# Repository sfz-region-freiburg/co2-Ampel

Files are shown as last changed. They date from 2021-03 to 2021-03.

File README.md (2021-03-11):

# CO2 Ampel
Hier findest du alle Informationen zur CO2 Ampel des Schülerforschungszentrum Region Freiburg e.V.

## Struktur
* [documentation](https://github.com/sfz-region-freiburg/co2-Ampel/tree/main/documentation) (Anleitungen und andere Dokumente)
* [electronic](https://github.com/sfz-region-freiburg/co2-Ampel/tree/main/electronics) (Schaltplan, PCB-Layout, EAGLE Daten, Gerber Daten)
* [firmware](https://github.com/sfz-region-freiburg/co2-Ampel/tree/main/firmware/CO2_Ampel_Display_1.5) (Arduino Code)
* [images](https://github.com/sfz-region-freiburg/co2-Ampel/tree/main/images) (Bilder und Grafiken)

## Die CO2 Ampel
CO2 Ampel

## Funktion der CO2 Ampel
* Ampelfarbe entsprechend der Raumluftqualität
* Bei überschreiten von 1000 ppm akustisches Signal (alle 5 Minuten) Blitzlicht (alle 5 Sekunden)
* Akkulaufzeit von ca. 20 Stunden

Hintergrundinformationen:
Außenluft hat üblicherweise eine CO2 Konzentration von 350 bis 450 ppm.

**Richtwerte für Raumluftqualität:**

kleiner 800 ppm | gut
800-1000 ppm | mittel
größer 1000 ppm | mäßig 
Spätestens jetzt sollte gelüftet werden.

## Details zum Aufbau 
[Findest du unter documentation](https://github.com/sfz-region-freiburg/co2-Ampel/tree/main/documentation)

# Gefördert durch:
Gisela und Erwin Sick Stiftung (https://www.sick-stiftung.org/ges/?target=_blank)

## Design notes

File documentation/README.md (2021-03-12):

# Aufbau der CO2 Ampel
Die CO2 Ampel besteht aus relativ wenigen Komponenten.

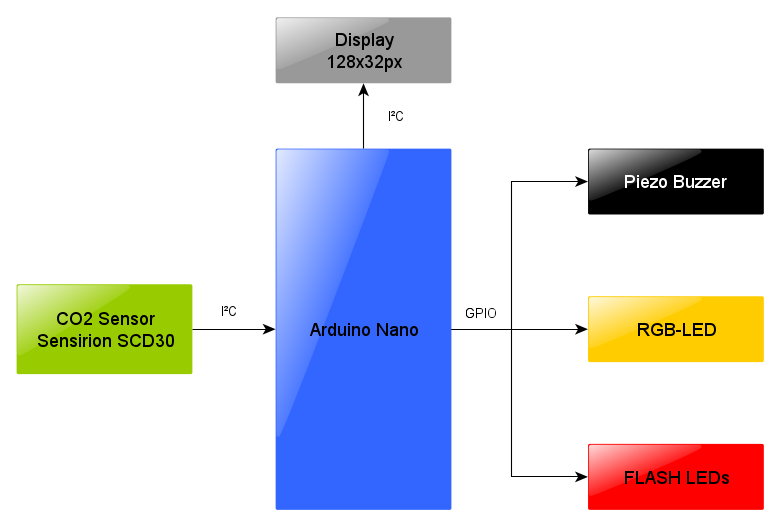
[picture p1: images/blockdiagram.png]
CO2 Ampel - Blockschaltbild


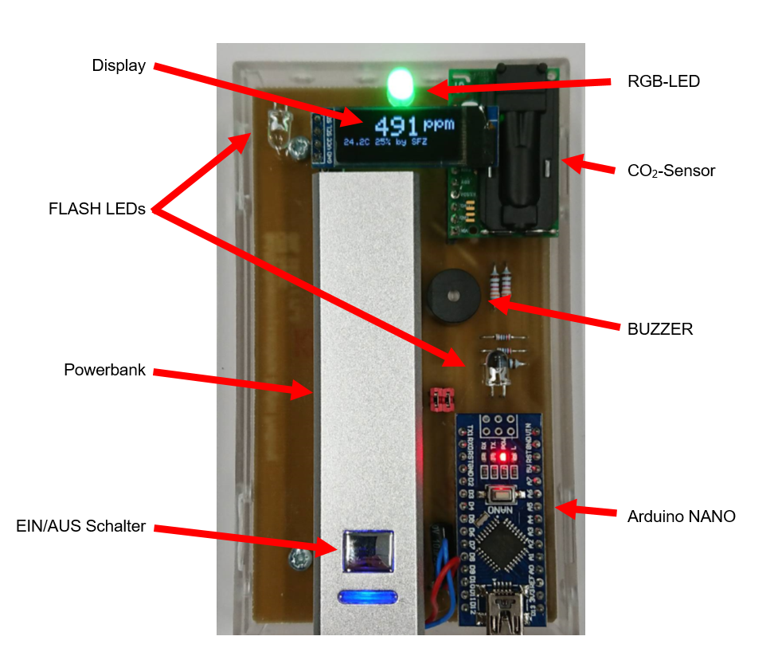
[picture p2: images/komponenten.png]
CO2 Ampel - Bild


### CO2 Sensor 
Der CO2 Sensor SCD30 von Sensirion misst über Infrarotstrahlung in seiner Messkammer die Konzentration an CO2 Partikeln in der Luft. Vereinfacht gesagt wird Licht im Infrarotbereich ausgesendet und abhängig von der CO2 Konzentration kommt mehr oder weniger von diesem Licht an einem Empfänger an. Je mehr CO2 in der Luft desto weniger Licht kommt an.

### Arduino Nano
Der Arduino Nano ist sozusagen die Schaltzentrale der CO2 Ampel, er bekommt vom CO2 Sensor die aktuelle Raumluftkonzentration, wertet diese aus, zeigt diese auf dem Display an und abhängig von den eingestellten Grenzwerten werden die RGB-LED, der Piezo Buzzer sowie die Flash LEDs geschalten. Die Kommunikation zwischen Arduino, CO2 Sensor und Display erfolgt über I2C, die LEDs und der Buzzer werden über digitale Ausgänge angesteuert.

### Display
Bei dem Display handelt es sich um ein sogenanntes Punktmatrix-Display mit einer Auflösung von 128 Punkten horizontal und 32 Punkten vertikal. Jeder dieser Punkte kann nun ein oder ausgeschalten werden. Um auf diesem Display nun Text oder Zahlen anzuzeigen wird eine Bibliothek verwendet die aus dem jeweiligen Symbol ein Punktmuster erzeugt. 

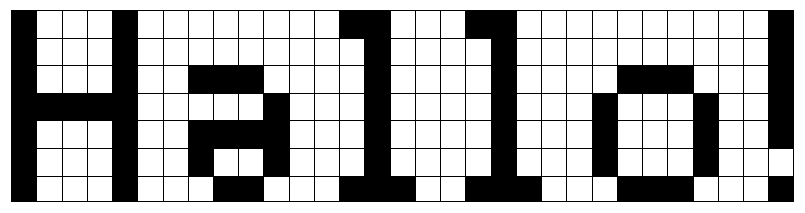
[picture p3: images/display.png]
Display - Hallo


Beispiel „Hallo!“

### RGB-LED
Bei der RGB-LED steht RGB für die drei Farben Rot, Grün und Blau. Es sind also drei LEDs in einem Gehäuse. Dies hat den Vorteil, dass man nicht nur die drei Farben hat, sondern auch diese drei Farben mischen kann. So erhält man zum Beispiel, wenn die Rote und die Grüne LED an sind die Farbe Gelb. 

Display - Hallo

### Piezo Buzzer
Ein Piezo Buzzer ist eine Art Lautsprecher. Durch Anlegen einer elektrischen Spannung schwingt der Piezo Kristall und bewegt so eine Membran, die diese mechanische Bewegung in Schallwellen umwandelt. Er dient als akustisches Signal bei Überschreiten des eingestellten Grenzwertes. Man muss also nicht immer auf die CO2 Ampel schauen.

### FLASH LEDs
Die beiden Flash LEDs sind sehr helle LEDs die rot leuchten. Sie werden immer nur kurz angeschaltet und erzeugen somit einen „Blitz“. Auch sie sollen auf die Überschreitung des Grenzwertes aufmerksam machen.

# Schaltplan
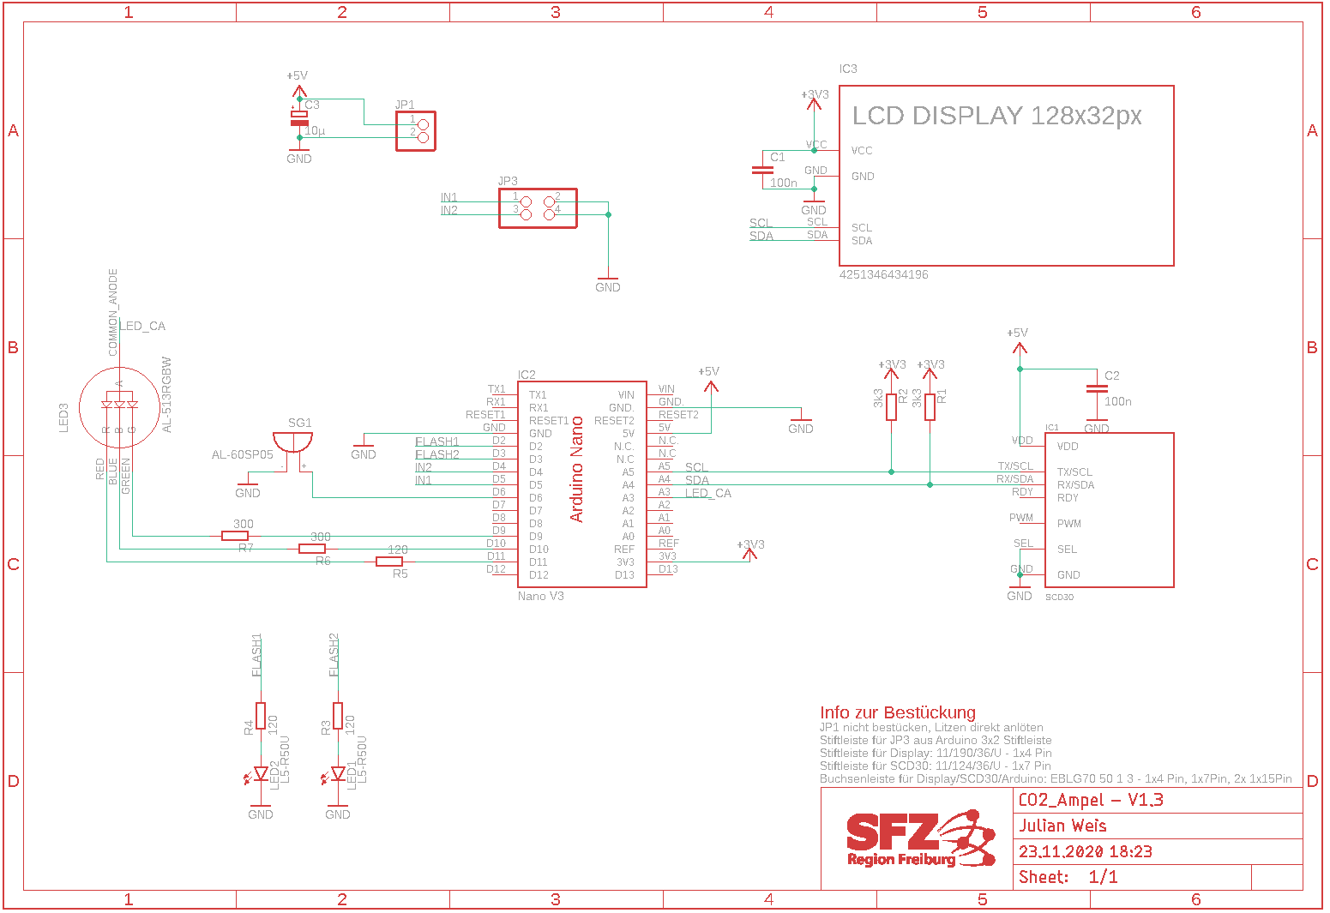
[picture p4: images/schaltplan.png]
CO2 Ampel - Schaltplan


# Komponentenliste
| Bauteil 						| Beschreibung | Bezeichnung | Anzahl | Bestelllink | Preis (ca) |
| ---- | ---- | ---- | ---- | ---- | ---- |
| CO2 Sensor 					| | IC1 		| 1 | | |
| Arduino Nano					| | IC2 		| 1 | | |
| Display 						| | IC3 		| 1 | | |
| RGB-LED 						| | LED3 		| 1 | | |
| Piezo Buzzer 					| | SG1 		| 1 | | |
| FLASH LEDs 					| | LED1, LED2 	| 2 | | |
| Vorwiderstand 120hm 			| | R3,R4,R5	| 3 | | |
| Vorwiderstand 300Ohm 			| | R6,R7		| 2 | | |
| I2C Pullup Widerstand 3300Ohm | | R1,R2 		| 2 | | |
| Gehäuse 						| | Strapubox 2515KL			| 1 | | |
| Powerbank mit Schalter 2200mAh | | 9,5 x 2,2 x 2,1 mm			| 1 | | |

# Gefördert durch:
Gisela und Erwin Sick Stiftung (https://www.sick-stiftung.org/ges/?target=_blank)

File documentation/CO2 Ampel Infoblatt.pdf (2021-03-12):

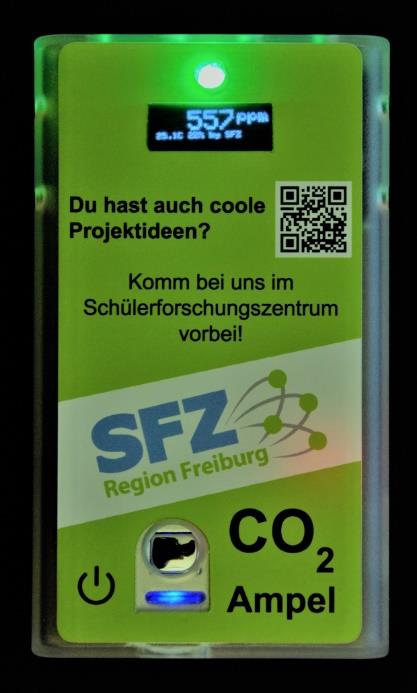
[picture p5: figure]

[1] Leitfaden für die Innenraumhygiene in Schulgebäuden

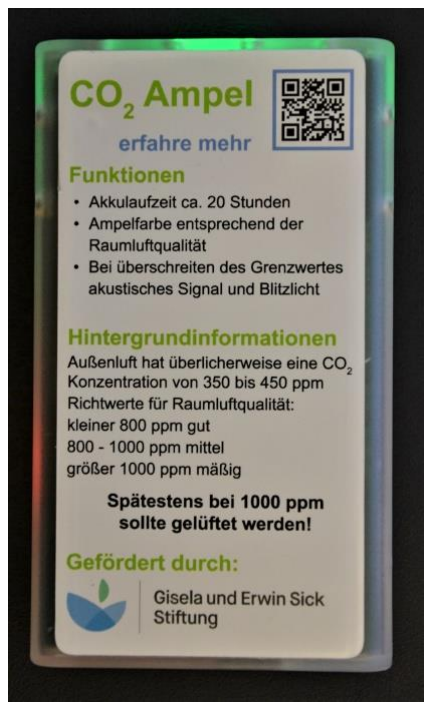
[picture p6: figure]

https://www.umweltbundesamt.de/publikationen/leitfaden-fuer-innenraumhygiene-in-schulgebaeuden

# CO₂ Ampel für das Klassenzimmer

Mit der CO₂ Ampel wird die CO₂ Konzentration im Klassenzimmer gemessen. Gerade in der jetzigen Zeit ist es wichtig regelmäßig zu lüften. Dabei hilft die CO₂ Ampel. Denn ein hoher CO₂ Wert in der Luft bedeutet auch, dass viele Aerosole in der Luft sind.

Eine OLED Anzeige gibt den aktuellen CO₂ Wert aus. Ist der Wert gut, leuchtet die RGB LED grün (unter 800 ppm). Verschlechtert sich der CO₂ Wert dann wechselt die RGB LED auf Orange (800 bis 1000 ppm) und anschließend auf Rot (über 1000 ppm). Ist der Grenzwert überschritten (über 1000 ppm), piept die CO₂ Ampel und zusätzliche LEDs im inneren blinken alle 5 Sekunden Rot, spätestens jetzt sollte gelüftet werden!

Richtwerte [1]

Bei Werten unter 800 ppm spricht man von hoher Raumluftqualität. Bei Werten zwischen 800 und 1000 ppm spricht man von mittlerer Raumluftqualität. Bei Werten von über 1000 ppm handelt es sich um eine mäßige Raumluftqualität. Spätestens jetzt sollte wieder gelüftet werden.
Frische Luft hat eine CO₂ Konzentration von 350 bis 450 ppm.

Richtig lüften

Wenn der Grenzwert erreicht wird ist es an der Zeit frische Luft in das Klassenzimmer zu lassen. Nun stellt sich die Frage kippen oder ganz öffnen? Um den CO₂-Wert schnell und effektiv verringern zu können muss man kurz Querlüften.

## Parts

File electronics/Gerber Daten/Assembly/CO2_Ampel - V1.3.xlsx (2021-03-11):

Qty | Parts | Value | Package
1 | IC2 |  | ARDUINO_NANO
1 | JP1 |  | 1X02
1 | JP3 |  | 2X02
1 | LED1 | L5-R50U | LED5MM_LIEGEND
1 | LED2 | L5-R50U | LED5MM_LIEGEND_GESPIEGELT
2 | C1, C2 | 100n | C050-025X075
1 | C3 | 10µ | E2-5
3 | R3, R4, R5 | 120 | 0207/10
2 | R6, R7 | 300 | 0207/10
2 | R1, R2 | 3k3 | 0207/10
1 | IC3 | EAN 4251346434196 | 0.91INCH_128X32_I2C_12X38MM
1 | LED3 | AL-513RGBW | LED-4_PIN
1 | SG1 | AL-60SP05 | F/TMB
1 | IC1 | SCD30 | SCD30

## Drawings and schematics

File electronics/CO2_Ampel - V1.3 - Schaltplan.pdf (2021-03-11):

# LCD DISPLAY 128x32px

A

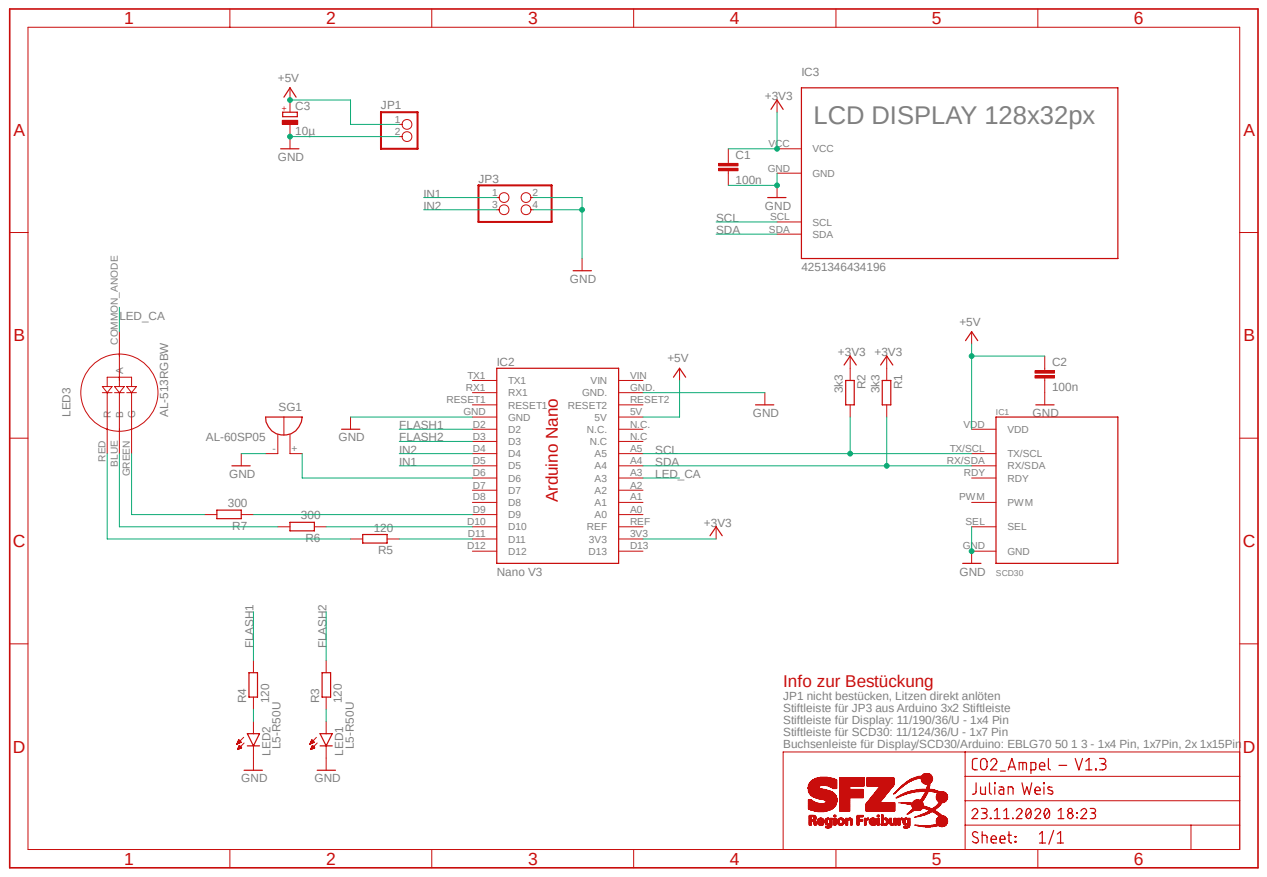
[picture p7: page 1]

TX/SCL
RX/SDA
RDY

Info zur Bestückung
JP1 nicht bestücken, Litzen direkt anlöten
Stiftleiste für JP3 aus Arduino 3x2 Stiftleiste
Stiftleiste für Display: 11/190/36/U - 1x4 Pin
Stiftleiste für SCD30: 11/124/36/U - 1x7 Pin
Buchsenleiste für Display/SCD30/Arduino: EBLG70 50 1 3 - 1x4 Pin, 1x7Pin, 2x 1x15Pin

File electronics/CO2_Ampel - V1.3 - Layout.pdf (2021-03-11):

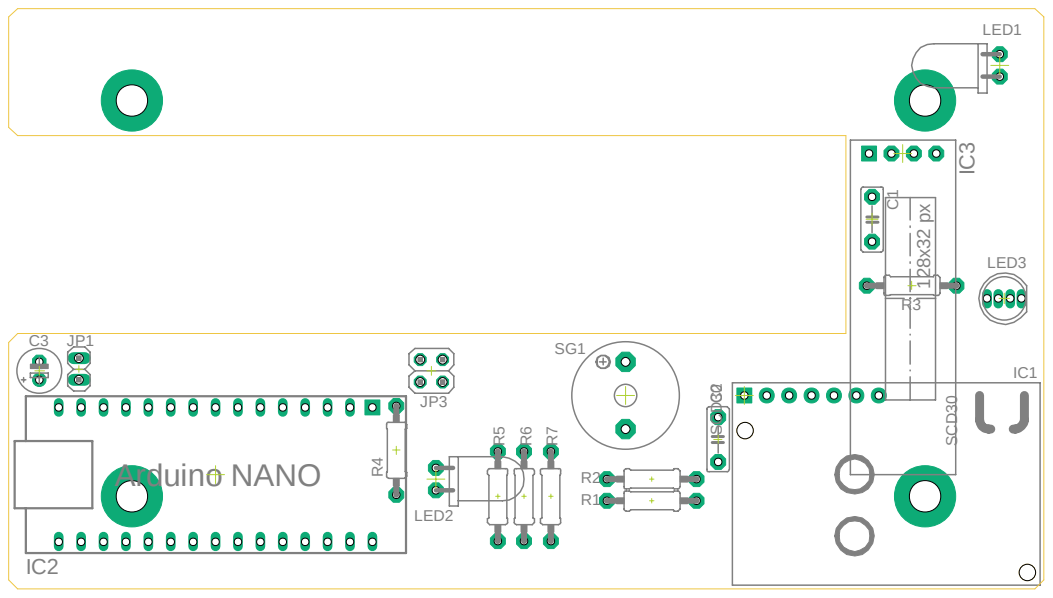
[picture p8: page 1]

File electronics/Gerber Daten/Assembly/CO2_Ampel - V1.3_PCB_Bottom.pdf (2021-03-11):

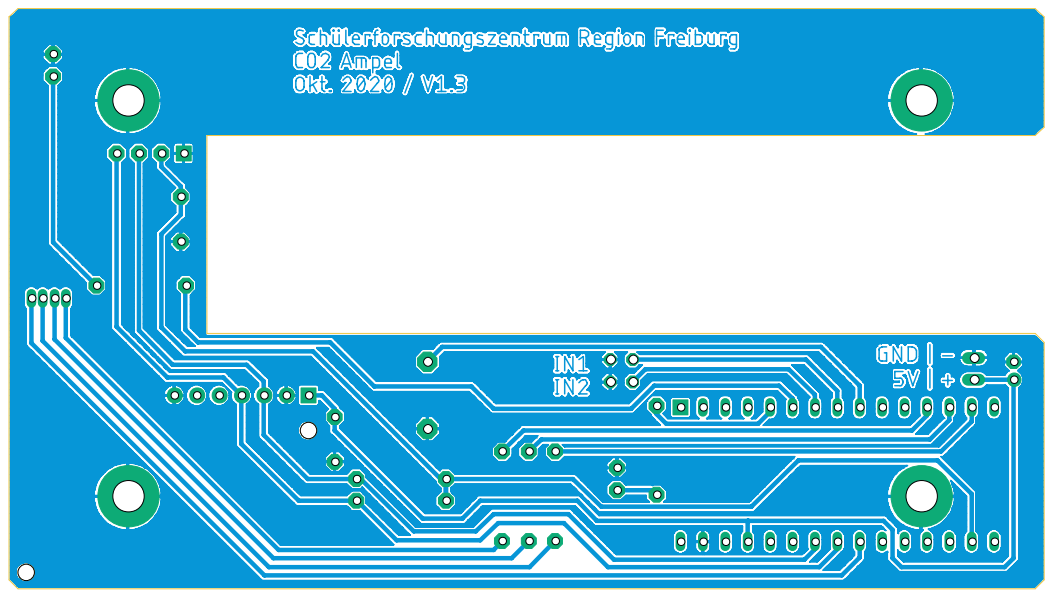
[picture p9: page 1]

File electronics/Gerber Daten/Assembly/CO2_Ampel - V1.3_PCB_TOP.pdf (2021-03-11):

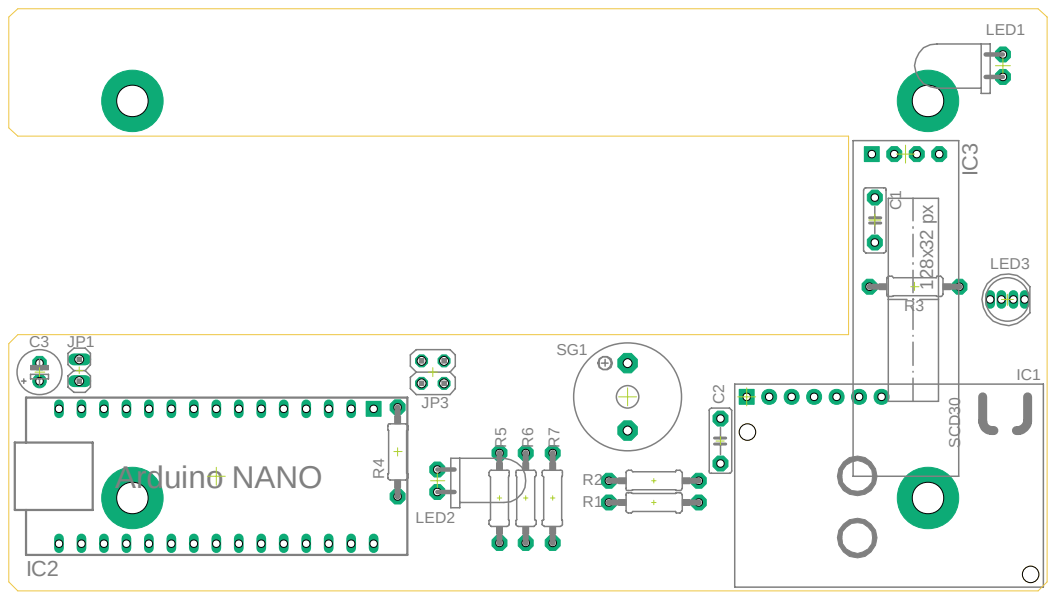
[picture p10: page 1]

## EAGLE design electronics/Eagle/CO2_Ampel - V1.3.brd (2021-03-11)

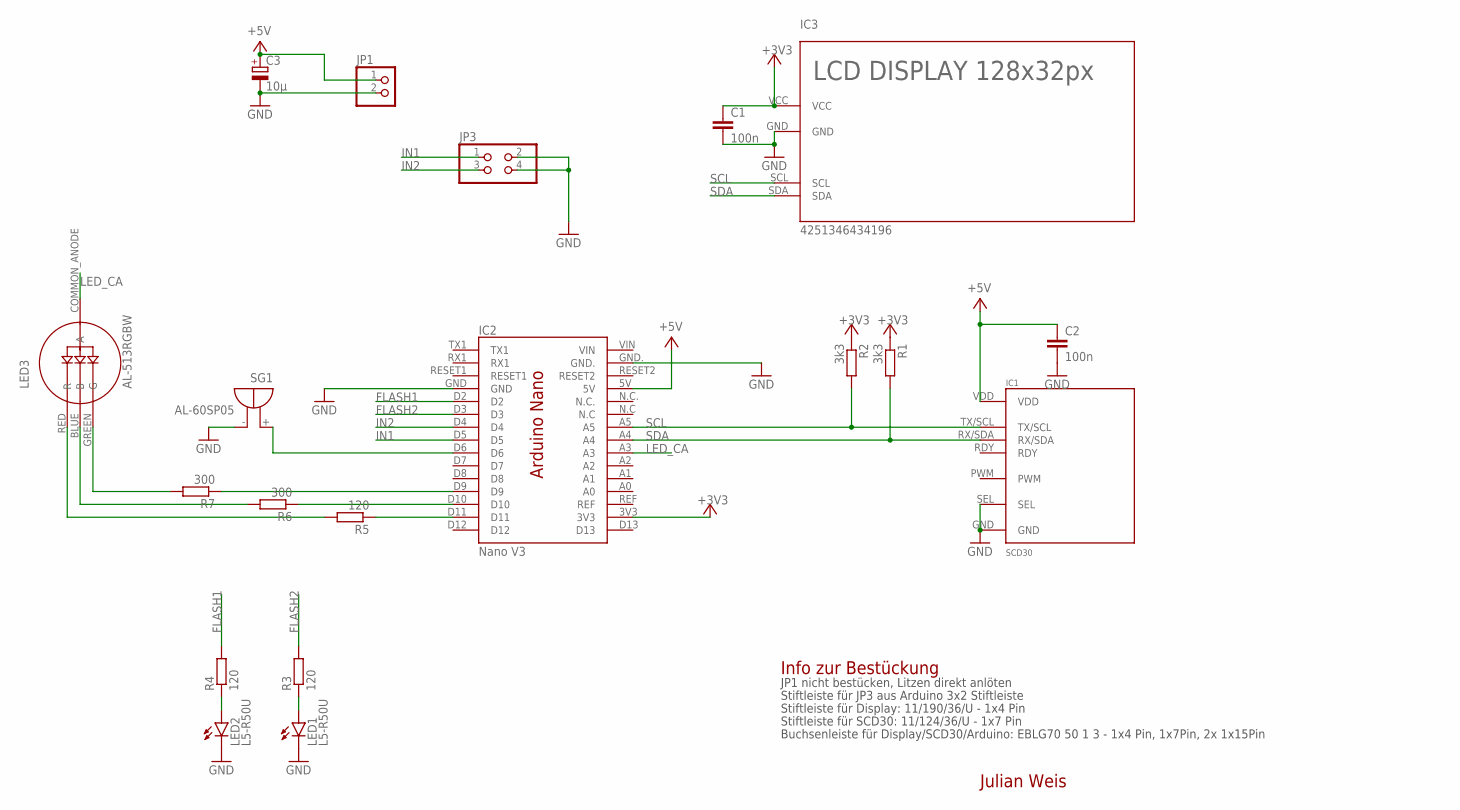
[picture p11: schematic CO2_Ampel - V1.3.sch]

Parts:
C1, C2: 100n; C050-025X075
C3: 10µ; E2-5
IC1: SCD30
IC2: Nano V3; ARDUINO_NANO
IC3: 4251346434196; 0.91INCH_128X32_I2C_12X38MM
JP1: PINHD-1X2; 1X02
JP3: PINHD-2X2; 2X02
LED1: L5-R50U; LED5MM_LIEGEND
LED2: L5-R50U; LED5MM_LIEGEND_GESPIEGELT
LED3: AL-513RGBW; LED-4_PIN
R1, R2: 3k3; 0207/10
R3, R4, R5: 120; 0207/10
R6, R7: 300; 0207/10
SG1: AL-60SP05; F/TMB

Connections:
+3V3: C1.1, IC2.3V3, IC3.VCC, R1.1, R2.1
+5V: C2.1, C3.+, IC1.VDD, IC2.5V, JP1.1
FLASH1: IC2.D2, R4.2
FLASH2: IC2.D3, R3.2
GND: C1.2, C2.2, C3.-, IC1.GND, IC1.SEL, IC2.GND., IC3.GND, JP1.2, JP3.2, JP3.4, LED1.K (C), LED2.K (C), SG1.-
IN1: IC2.D5, JP3.1
IN2: IC2.D4, JP3.3
LED_CA: IC2.A3, LED3.COMMON_ANODE (A)
unnamed: LED3.RED (R), R5.2
unnamed: LED3.BLUE (B), R6.2
unnamed: LED2.A, R4.1
unnamed: LED1.A, R3.1
unnamed: LED3.GREEN (G), R7.2
unnamed: IC2.D9, R7.1
unnamed: IC2.D10, R6.1
unnamed: IC2.D11, R5.1
unnamed: IC2.D6, SG1.+
SCL: IC1.TX/SCL, IC2.A5, IC3.SCL, R2.2
SDA: IC1.RX/SDA, IC2.A4, IC3.SDA, R1.2

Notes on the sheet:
Stiftleiste für Display: 11/190/36/U - 1x4 Pin
Stiftleiste für SCD30: 11/124/36/U - 1x7 Pin
Buchsenleiste für Display/SCD30/Arduino: EBLG70 50 1 3 - 1x4 Pin, 1x7Pin, 2x 1x15Pin
Info zur Bestückung
Stiftleiste für JP3 aus Arduino 3x2 Stiftleiste
JP1 nicht bestücken, Litzen direkt anlöten

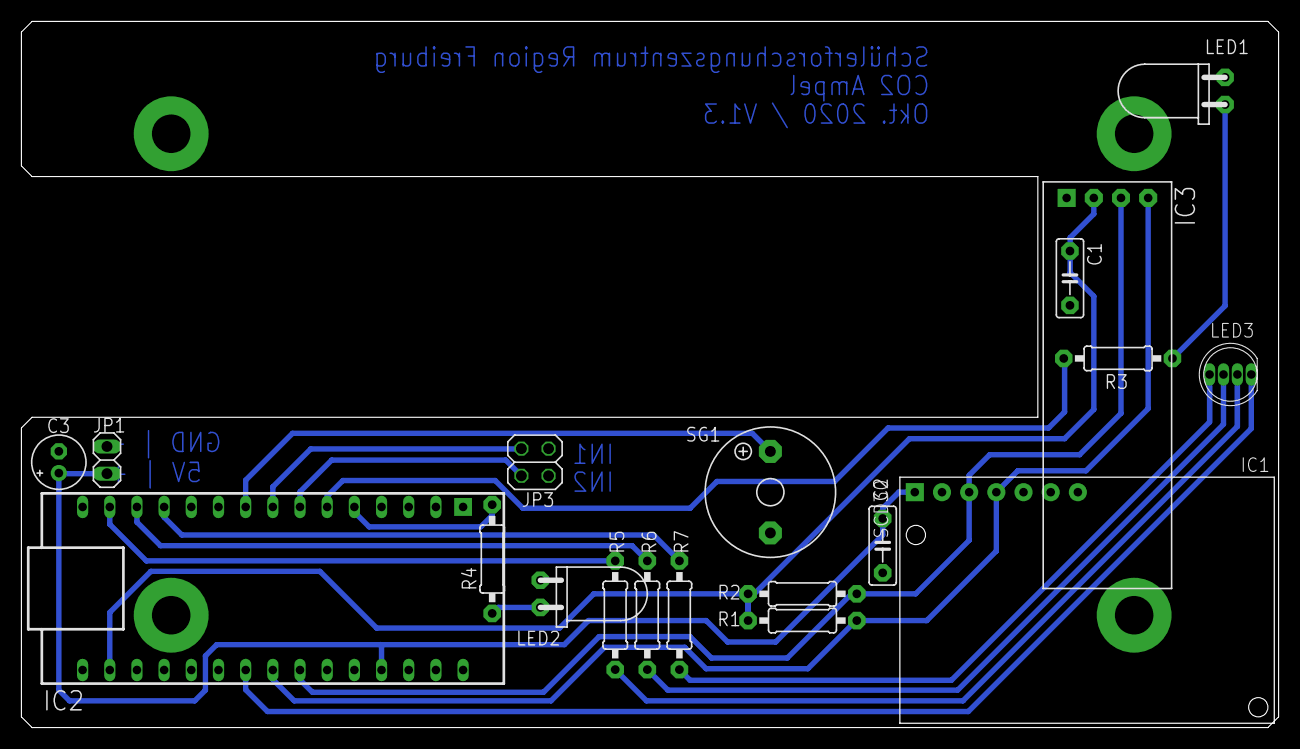
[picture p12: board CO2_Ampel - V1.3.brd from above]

Board: 2 copper layers, 117.5 x 66.0 mm, 19 parts (0 on the bottom side), 19 nets.

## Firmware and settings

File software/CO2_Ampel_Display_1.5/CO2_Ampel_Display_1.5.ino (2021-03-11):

/*
  CO2 Ampel
  By: Sülerforschungszentrum Region Freiburg
  Date: October, 2020
  Version: V1.5

  Functiondescription:
  - Reads CO2, humidity and temperature from the Sensirion SCD30 Sensor
  - Display readings on an 128x32 OLED Display
  - Generates an alarm (tone and LED flash) when threashold is excceded
  -





*/

#define SWversion 1.5



#include <SPI.h>
#include <Wire.h>
#include "SparkFun_SCD30_Arduino_Library.h" //https://github.com/sparkfun/SparkFun_SCD30_Arduino_Library
#include "Adafruit_SSD1306.h" // https://github.com/adafruit/Adafruit_SSD1306
#include "Adafruit_GFX.h" //needed by Adafruit_SSD1306 library https://github.com/adafruit/Adafruit-GFX-Library also needs https://github.com/adafruit/Adafruit_BusIO


//Function announcment
float average (float * array, unsigned int len);
void setRgbLed(float co2Avg);
void alarm(float co2Avg);
bool calibration(unsigned int co2concentration);

//DISPLAY SETTINGS
#define SCREEN_WIDTH 128 // OLED display width, in pixels
#define SCREEN_HEIGHT 32 // OLED display height, in pixels
#define DISPLAY_ADR 0x3c
// Declaration for an SSD1306 display connected to I2C (SDA, SCL pins)
#define OLED_RESET     -1 // Reset pin # (or -1 if not used)
Adafruit_SSD1306 display(SCREEN_WIDTH, SCREEN_HEIGHT, &Wire, OLED_RESET, 100000, 100000);
//Print buffer for alignment of CO2 value on the Display
char printBuffer[] = {"            "};



//PIN DEFINITIONS
#define LED_R 11  // RGB-LED RED, Pin D11
#define LED_G 9  // RGB-LED GREEN, Pin D9
#define LED_B 10  // RGB-LED BLUE, Pin D10
#define LED_CA A3 // RGB-LED Common Anode, Pin A3
#define BUZZER 6  // Buzzer pin D6
#define FLASH1 2 // Red Flash LED, pin D2, near Display
#define FLASH2 3 // Red Flash LED, pin D3, near Arduino
#define IN1 5 // Jumper input IN1, not used at the moment
#define IN2 4 // Jumper input IN2, not used at the moment

//BUZZER SETTINGS
#define BUZZER_INTERVAL 300000 //Butzzer interval in ms, default 300000, every 5 Minutes
#define BUZZER_LEVEL 1000     // CO2 Level for buzzer
#define BUZZER_TONE_LENGTH 1000 // in ms

//FLASH SETTINGS
#define FLASH_INTERVAL 5000 // in ms
#define FLASH_LENGTH 150 // in ms

// RGB LED FADING SETTINGS
#define GREEN_LOWER_LIMIT 0
#define GREEN_UPPER_LIMIT 1000
#define RED_LOWER_LIMIT   800
#define RED_UPPER_LIMIT   1000
#define FADING false // FADING false = hard color changes, FADING true = color fades from 0 to 255 within the LIMITs


//VARIABLES FOR SENSOR DATA
float co2 = 0;
float temperature = 0;
float humidity = 0;
float co2Avg = 0;
int temperaturOffset = 3;
uint16_t calibConcentration = 450; // This value is set as concentration during calibration process, default is 400 (normal average outside air)

unsigned long nextNewData = 0;


//ROLLING AVERAGE BUFFER FOR CO2 VALUE
#define AVERAGING_NUMBER 15 // Number of elements for averaging, default 15 (equals 30s averaging)
float co2LastMinute [AVERAGING_NUMBER];
unsigned char co2LastMinutePointer = 0;

//TIMESTAMPS FOR BUZZER & FLASH
unsigned long lastExceed = 0;
unsigned long nextTone = 0;
unsigned long nextFlash = 0;


//Display Strings
char calibrationScrolling1[] = "          Now place jumper IN2 for calibration or remove IN1 to exit.   Sensor must be exposed to outside air for more than 5 minutes for calibration!";

//Declaration of SCD30 instence
SCD30 airSensor;


void setup()
{
  //PIN mode definition
  pinMode(LED_R, OUTPUT);
  pinMode(LED_G, OUTPUT);
  pinMode(LED_B, OUTPUT);
  pinMode(LED_CA, OUTPUT);
  pinMode(FLASH1, OUTPUT);
  pinMode(FLASH2, OUTPUT);
  pinMode(IN1, INPUT_PULLUP);   //not used at the moment
  pinMode(IN2, INPUT_PULLUP);   //not used at the moment
  pinMode(BUZZER, OUTPUT);



  //Set initial output values
  digitalWrite(FLASH1, LOW);  //Flash LED OFF
  digitalWrite(FLASH2, LOW);  //Flash LED OFF
  digitalWrite(BUZZER, LOW);  //Buzzer LED OFF
  digitalWrite(LED_R, HIGH);    // RGB-LED red OFF
  digitalWrite(LED_G, HIGH);    // RGB-LED green OFF
  digitalWrite(LED_B, HIGH);    // RGB-LED blue OFF
  digitalWrite(LED_CA, HIGH); //LED Common Anode ON



  //Bootdelay for propper sensor boot
  delay(2000);

  //Start serial connection for project / debug information
  Serial.begin(115200);
  Serial.println("CO2 Ampel");
  Serial.println("Schülerforschungszentrum Region Freiburg");

  //Start I2C
  Wire.begin();
  Wire.setClock(100000);

  //CO2 Sensor Init
  if (airSensor.begin() == false)
  {
    Serial.println("Air sensor not detected. Please check wiring.");
    while (1);
  }

  delay(100);

  //Display Init
  if (!display.begin(SSD1306_SWITCHCAPVCC, 0x3C)) {
    Serial.println("SSD1306 allocation failed. Please check wiring.");
    while (1);
  }
  //Clear display
  display.clearDisplay();
  display.display();


  if (digitalRead(IN1) == LOW && digitalRead(IN2) == HIGH) {
    calibration(calibConcentration);
  }


  //
  //










}

void loop()
{




  //Check if new sensor data is available, the SCD30 has data ready every two seconds
  if (nextNewData < millis() && airSensor.dataAvailable())
  {




    nextNewData = millis() + 2000; // only request new data when the SCD30 potentially has new Data available

    //Read sensor data
    co2 = airSensor.getCO2();
    temperature = airSensor.getTemperature() - temperaturOffset;
    humidity = airSensor.getHumidity();

    //Update CO2 rolling average buffer
    co2LastMinute[co2LastMinutePointer] = co2;
    co2LastMinutePointer = (co2LastMinutePointer + 1) % AVERAGING_NUMBER;

    //Calculate average
    co2Avg = average(co2LastMinute, AVERAGING_NUMBER);




    //UPDATE DISPLAY
    display.clearDisplay();
    display.setTextSize(3);
    display.setTextColor(WHITE, BLACK);
    display.setCursor(0, 0);



    sprintf(printBuffer, "%5d", (unsigned int)co2Avg);
    display.print(printBuffer);
    //    display.print(co2Avg, 0);
    delay(10);

    display.setTextSize(2);
    delay(10);
    display.setCursor(92, 0);
    delay(10);
    display.print("ppm");
    delay(10);
    display.setTextSize(1);
    delay(10);
    display.setCursor(0, 24);
    delay(10);
    display.print(temperature, 1);
    delay(10);
    display.print("C ");
    delay(10);
    display.print(humidity, 0);
    delay(10);
    display.print("% by SFZ");
    delay(10);


    digitalWrite(IN1, HIGH);
    digitalWrite(IN2, LOW);

    if (co2LastMinutePointer % 2 == 0) {
      display.drawPixel(127, 31, WHITE);
      delay(10);
      display.invertDisplay(false);
      delay(10);

      digitalWrite(IN1, LOW);
      digitalWrite(IN2, HIGH);


    }
    else if (co2Avg > BUZZER_LEVEL) {

      display.invertDisplay(true);
      delay(10);



    }

    // Hier bleibt es hängen!
    display.display();

    digitalWrite(IN1, HIGH);
    digitalWrite(IN2, HIGH);



    //Set RGB led according level definitions
    setRgbLed(co2Avg);


    //Evaluate if alarm threshtold is exceeded and genatate tone and/or red flash according to settings
    alarm(co2Avg);

  }
  else {


    digitalWrite(IN1, LOW);
    digitalWrite(IN2, LOW);

    //Delay to not stress SCD30, if no new data available wait 100ms before the next request
    delay(100);

  }

}


//Set RGB led according level definitions
void setRgbLed(float co2Avg) {
  if (FADING == true) {
    //SET RGB LED ACCORDING TO DEFINED LEVEL SETTINGS WITH SMOOTH FADING
    analogWrite(LED_G, map(constrain(co2Avg, GREEN_LOWER_LIMIT, GREEN_UPPER_LIMIT), GREEN_LOWER_LIMIT, GREEN_UPPER_LIMIT, 0, 255));
    analogWrite(LED_R, map(constrain(co2Avg, RED_LOWER_LIMIT, RED_UPPER_LIMIT), RED_LOWER_LIMIT, RED_UPPER_LIMIT, 255, 0));
  }
  else {
    //SET RGB LED ACCORDING TO DEFINED LEVEL SETTINGS WITH HARD COLOR CHANGES
    if (co2Avg < GREEN_UPPER_LIMIT) {
      digitalWrite(LED_G, LOW);
    }
    else {
      digitalWrite(LED_G, HIGH);
    }
    if (co2Avg > RED_LOWER_LIMIT) {
      digitalWrite(LED_R, LOW);
    }
    else {
      digitalWrite(LED_R, HIGH);
    }
  }
}


//Evaluate if alarm threshtold is exceeded and genatate tone and/or red flash
void alarm(float co2Avg) {
  // ALARM LEVEL
  if (co2Avg > BUZZER_LEVEL) {
    lastExceed = millis();
    if (lastExceed > nextFlash && nextNewData > (lastExceed + FLASH_LENGTH))
    {
      nextFlash = lastExceed + FLASH_INTERVAL;
      digitalWrite(FLASH1, HIGH);
      digitalWrite(FLASH2, HIGH);
      delay(FLASH_LENGTH);
      digitalWrite(FLASH1, LOW);
      digitalWrite(FLASH2, LOW);
    }
    if (lastExceed > nextTone  && nextNewData > (lastExceed + BUZZER_TONE_LENGTH)) {
      nextTone = lastExceed + BUZZER_INTERVAL;
      digitalWrite(BUZZER, HIGH);
      delay(BUZZER_TONE_LENGTH);
      digitalWrite(BUZZER, LOW);
    }
  }
  else {
    nextTone = lastExceed;
    nextFlash = lastExceed;
  }
}


bool calibration(unsigned int co2concentration) {

  while ( digitalRead(IN1) == LOW &&  digitalRead(IN2) == HIGH) {

    digitalWrite(LED_R, HIGH);    // RGB-LED red OFF
    digitalWrite(LED_G, HIGH);    // RGB-LED green OFF
    digitalWrite(LED_B, LOW);    // RGB-LED blue ON
    digitalWrite(LED_CA, HIGH); //LED Common Anode ON


    display.clearDisplay();
    display.setTextWrap(false);
    display.setTextSize(2);
    //    display.setTextColor(WHITE);
    display.setTextColor(WHITE, BLACK);
    display.setCursor(0, 0);
    delay(10);
    display.print("CALIB");
    delay(10);
    display.setTextSize(1);
    delay(10);
    display.setCursor(62, 0);
    delay(10);
    display.print(calibConcentration);
    display.print("ppm V");
    display.print(SWversion);
    delay(10);
    display.setTextSize(2);
    delay(10);
    display.display();

    for (unsigned int i = 0; i < strlen(calibrationScrolling1) - 10; i++) {
      display.setCursor(0, 16);
      delay(10);
      display.print(&calibrationScrolling1[i]);
      delay(10);
      display.display();
      delay(200);

      if ( digitalRead(IN1) == LOW &&  digitalRead(IN2) == LOW) break;
      if ( digitalRead(IN1) == HIGH) {
        digitalWrite(LED_B, HIGH);    // RGB-LED blue OFF
        return false;
      }
    }






    if ( digitalRead(IN1) == LOW &&  digitalRead(IN2) == LOW) {
      display.fillRect(0, 16, 128, 16, BLACK);
      display.setCursor(0, 16);
      delay(10);
      display.setTextSize(1);
      delay(10);
      display.print("CALIB starts in ");
      delay(10);
      display.setCursor(0, 24);
      display.print("Remove jumper to EXIT");
      display.display();



      for (int i = 0; i < 300; i++) {
        display.setCursor(100, 16);
        delay(10);
        display.print(300 - i);
        delay(10);
        display.print("s");
        delay(10);
        display.display();
        delay(900);

        if ( digitalRead(IN1) == HIGH ||  digitalRead(IN2) == HIGH) {
          digitalWrite(LED_B, HIGH);    // RGB-LED blue OFF
          return false;
        }
      }

      airSensor.setForcedRecalibrationFactor(calibConcentration);
      digitalWrite(LED_B, HIGH);    // RGB-LED blue OFF
      return true;
    }

  }
  digitalWrite(LED_B, HIGH);    // RGB-LED blue OFF
}



//AVERAGE CALCULATION OF AN FLOAT ARRAY
float average (float * array, unsigned int len)  // assuming array is float.
{
  float sum = 0L ;  // sum will be larger than an item, float for safety.
  for (int i = 0 ; i < len ; i++)
    sum += array [i] ;
  return  ((float) sum) / len ;  // average will be fractional, so float may be appropriate.
}

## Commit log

2021-03-11 Initial upload
    [CO2_Ampel - V1.3.brd, CO2_Ampel - V1.3.sch]
2021-03-11 README.md update der Formatierung
2021-03-11 Neue Ordnerstruktur
    [CO2_Ampel - V1.3.brd, CO2_Ampel - V1.3.sch, CO2_Ampel - V1.3.xlsx]
